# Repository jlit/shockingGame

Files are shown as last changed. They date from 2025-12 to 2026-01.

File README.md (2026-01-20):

# R^4 - A Shocking Game
A reaction, recall, roulette, and random game with consequences



# Description
This is an improvement over the ["Lightning Reaction Reloaded - Shocking Game"](https://www.amazon.com/dp/B0006B2Q50?ref=ppx_yo2ov_dt_b_fed_asin_title) available for $40 online.  In that game, players press the button on their controller when the game's random delay indicates.  The last player to respond gets an electric shock.  The game supports 2-4 players.

This improved version supports 2-5 players and adds three new game modes: "Recall", "Roulette", and "Random".  Recall similar to the old [Simon Game](https://en.wikipedia.org/wiki/Simon_(game)) from the 1970s.  In this mode, players must repeat an ever longer sequence.  This first player to mess up the sequence is shocked.  Roulette is a verison of Russian Roulette where one player presses their button and may or may not be shocked.  Random mode always shocks one player at random each round.

# Features
- Reaction Time game mode
- Recall Sequence game mode
- Russian Roulette game mode
- Random game mode
- Up to 5 players
- Variable intensity adjustment knob to control shock
- Digital intensity display
- 30 multi-colored LEDs
- Sound

# Play
Insert 8 AA batteries into the compartment on the bottom of the game.  Begin by turning the power switch to On.  A series of LED annimations should appear and the Intensity digital display should show a number from 1.50 to 6.90.  

__IMPORTANT: If the display shows more than 7 (volts) do not play the game.__

Turn the intensity knob to the desired level.  The digital display shows the voltage.  Under 3 voltages is barely detectable.  3 volts is "normal".  Use above 3 volts at your own risk.  6.9 volts is the maximum and hurts.

## Reaction Mode
Turn the game mode knob to Reaction and press the Number of Players button until the desired number (2-5) of player LEDs illuminate.  An LED animation (green sequence of lights for each active player) will illuminate for each player.  Each player should pick up a controller near illuminated LEDs and grasp it so that their hand touches both aluminum strips.  Turn the intensity knob to the desired level.  See above.

Press the Start button (big white button in center) to start a round of play.  A sound and animation will play, followed by a random length of quiet time (2-10 seconds) and then all the LEDs will turn white and a beep will sound.  Each player should press the button on the their controller as soon as they sense the lights and sound.  The LEDs will illuminate to indicate the order the buttons were pressed.  The player with the fastest reaction time will show 1 blue LED, the seconds fastest 2 blue LEDs, etc. until the last player.  That player will show 4 blinking red LEDs and will have received a 100 ms shock.

The game has cheat detection.  Any player who has their button depressed when the game switches from delay to all white LEDs will be deemed a cheater.  All 4 of their LEDs will blink red and they will receive a 1 second shock for cheating.

After 5 seconds, the game will again display LED animation and wait for the next press of the Start button for another round.

## Recall Mode
Turn the game mode knob to Recall and select the desired number of players (2-5).  An LED animation will illuminate (lighting up each player's LEDs in a random order).  Each player should pick up a controller near illuminated LEDs and grasp it so that their hand touches both aluminum strips.  Turn the intensity knob to the desired level.  See above.

Press the Start button (big white button in center) to start a round of play.  A single player's LEDs will illuminate in a color specific to that player, and a short sound will play.  That player has 5 seconds to press their button once.  If they do not press their button within 5 seconds their LEDs will flash red and they will receive a shock.  If a different player presses their button they will receive the same treatment.  Either way, the game is over at this point.  

If the proper player presses their button (and only that player), the game progresses.  The same player's sound and LED will again illuminate, followed by a second player's LED and sound (or maybe the first player's twice -- it is random).  The players again have 5 seconds between each item in the sequence to press their button.  If the sequence is not repeated correctly, the offending player is shocked, their LEDS are turned red and the game is over.  If the sequence is mimicked correctly, the game continues with 3 items in the sequence, etc. until a player makes a mistake.  Note: the time between items in the sequence gets slightly shorter with each round.

Five seconds after a mistake, the game will again display LED animation and wait for the next press of the Start button for another round.

## Russian Roulette Mode
Turn the game mode knob to Roulette and select the desired number of players (2-5).  An LED animation will illuminate (each player's 4 LEDs blue, one at a time, rotating around).  Each player should pick up a controller near illuminated LEDs and grasp it so that their hand touches both aluminum strips.

Press the Start button (big white button in center) to start a round of play.  In this mode, each player's LEDs illuminate white and the game waits for an active player to press their controller button.  When they do, they will receive a shock and their LEDs with blink red if they are the "target" player, otherwise their LEDs will turn green and no one will be shocked.

After 5 seconds, the game will again display the LED animation and wait for the next button press with a new random target player.

## Random Mode
Turn the game mode knob to Random and select the desired number of players (2-5).  An LED animation will illuminate (each player's 4 LEDs cyan, in a random order).  Each player should pick up a controller near illuminated LEDs and grasp it so that their hand touches both aluminum strips.

Press the Start button (big white button in center) to start a round of play.  A sound and animation will play, followed by a random length of quiet time (2-6 seconds) and then all the LEDs will turn white.  At this point,  one player will be shocked and their LEDs will turn red.  

After 5 seconds, the game will again display the LED animation and wait for the next button press with a new random target player.

# Build
The game uses an Arduino micro-controller to handle the logic.  The shock circuit is harvested from a toy shock pen and use a flyback transformer and oscillator operating at between 2.5-6 volts.  The controllers house a momentary button and two polished aluminum electrodes along the sides.  The base houses the control knobs, voltage display, LEDs, and center start button.  Most of the parts are 3D printed in PLA.

# Parts List
- [Arduino R4 Minima](https://www.amazon.com/Arduino-UNO-Minima-ABX00080-Connector/dp/B0C78K4CD4/ref=sr_1_3)
- [Battery Holder (8 AA)](https://www.amazon.com/dp/B07WP1CYYW)
- [Mini ON and Off Rocker Switch 12V 20A T85 2 Pin SPST](https://www.amazon.com/dp/B07S2QJKTX)
- [Momentary Tactile Push Button, 12 x 12 mm x 4.3 mm](https://www.amazon.com/TWTADE-Momentary-Tactile-Button-Switch/dp/B07CG6HVY9)
- [1 Pole 4 Position Rotary Switch (for game mode)](https://www.amazon.com/dp/B07JLRM2L7)
- [1K Linear Rotary Potentiometer (for intensity)](https://www.amazon.com/dp/B082FCFSHX)
- [LM2596 DC-DC Buck Converter Step Down Module Power Supply](https://www.amazon.com/Zixtec-LM2596-Converter-Module-1-25V-30V/dp/B07VVXF7YX)
- [3 Wire 0.36" DC 0~30V Digital Voltmeter Digital Red LED Display](https://www.amazon.com/dp/B079N98PY4)
- [WS2812B IC RGB Individual Addressable LED Strip Light](https://www.amazon.com/LOAMLIN-WS2812B-Individually-Addressable-Waterproof/dp/B0956C7KFR)
- [Momentary Stainless Steel Push Button On/Off (High Head)](https://www.amazon.com/dp/B08L49F7DV) (Quantity 6)
- [Aluminum Flat Plate Bar Stock 3 x 10 x 305mm T6511](https://www.amazon.com/dp/B0CZ4F77TL)
- [22 Gauge 4 Conductor Electrical Wire](https://www.amazon.com/dp/B0CFJXMDT3)
- [5V 6 Channel Relay Optocoupler Isolation Module](https://www.amazon.com/dp/B08RRTHTYQ)
- [Toy Shock Pen](https://www.amazon.com/dp/B0DZWW5TX7)
- Wire, solder, PLA filament, zip ties, screws, etc.

# Electrical Circuit
The game uses 8 AA batteries for 12v DC to power the Ardunio and a LM2596 DC-DC Buck Converter.  The output of the buck converter is controlled by an "intensity" rotary 0-1k poteniometer knob, resulting in 2-7v DC output to drive the shock circuits.  The output voltage is displayed on a 3 digit 8-segment display.  The shock circuit uses a flyback transformer (looks like a blue capacitor) and a small oscillator.  A single shock circuit is controlled by and isolated from the Arduino via an opto-isolated relay and the output from the shock circuit is relayed to a player's controller also via opto-isolated relays.  All buttons and switches are connected to GPIO pulled up pins on the Arduino and complete the circuit to ground.  The WS2812 LED strip uses 5v power from the Arduino and a single data GPIO pin to control the individually addressable LEDs.



 # CAD Designs
 All components of the game were designed in Autodesk Fusion 360.
 









# Build
## 3D print all the parts
- Base
- Base Top
- Battery Cover
- Start Button
- Start Button Mount
- Controller Handle (x5)
- Controller Cover (x5)
- Storage tray

## Shock Circuits
- To build the shock circuit, disassemble a toy shock pin by unscrewing the tip and breaking the middle black portion from the silver top portion.
- Using pliers for grip, pull the black tube out of the top.
- There will be a blue capacitor, a very small circuit board with a white oscillator dot in the middle, three small batteries, and a spring.
- Remove the blue capacitor by unbending the lower terminal wire.
- Solder two terminals of the capacitor to the pads on the circuit board they were touching when in the pen.
- Solder a wire to the other terminal of the capacitor.
- Solder two wires to the other two pads on the other end of the circuit board.
- If you apply 3-6 volts to those two wires and then touch the ground wire and the 3rd terminal of the capacitor you will receive a shock.
- Reuse the batteries for some other project.



## Controllers
- Prepare to build the controllers by cutting the aluminum bar stock to 60mm lengths for each electrode.  
- Drill and tap a hole for an M3 screw in each.  The holes should by 7mm from the top and 7mm from the outside edge of each bar.





- Round the outside corners of each and polish.
- Cut the 4-conductor wire into 5 30" lengths.
- Assemble all the parts (including 3mm screws and washers)



- Cut the wires from the buttons and remove any remaining heat shrink.
- Strip 90mm of the outside cover from one end of each wire and strip and tin the ends of each conductor.  
- For each controller,
  - Thread the button into the top of the controller.
  - insert the wires from the bottom.  
  - Solder two wires (red and white) to the two button terminals.
  - Using and M3 screw and washer, secure the other two wires to two electrode bars.
  - Secure a zip-tie around the 4-conductor wire where it exits the hole in the bottom of the controller.
  - Place the bars into the slots on the cover and slide the cover under the top of the controller.
  - Secure the cover in place with one M3 screw.

## LEDs
- Cut the WS2812 LED strip into 4 lengths of 4 LEDs.  Be sure to cut at designated cut lines on the strip.
- Solder 3 wires (5v, data, ground) between each strip.  Be certain to keep the arrows pointing in the same direction.
- Using a hot glue gun, glue the strips into the top of the game so that the LEDs align with the holes.
- Cover each strip with tape.





## Start Button
- CA glue the 12mm button switch to the start button mount panel with the pins sticking through the holes.
- Solder wires to two pins on one side of the switch.
- Place the start button into the top, cover, and attach the switch cover to the top with 5 screws.

## Knobs and Switches
- Solder wires to the terminals of the 3 position rotary game mode switch.
- Insert rotary switch into the top, place the label, secure with the provided washer and nut, and attach a knob.
- For the number of players button, insert the button into the top, place the label, secure with the provided nut from below.
- For the intensity control, the on-board potentiometer on the LM2596 DC-DC Buck Converter needs to be replaced with the 1k rotary potentiometer.
- Using a soldering iron, remove the blue pot.
- Solder wires to the 3 terminals of the 1k rotary pot and solder the other ends to the LM2596.
- Insert the rotary pot into the top, place the label, secure with the provided washer and nut, and attach a knob.
- Insert the digital voltage display into the top and secure with 2 m2 screws.
- Insert the power toggle switch into the side of the top unit.

## Wiring
- Thread each controller wire into the holes on the side of the top unit.
- Connect the switches, controllers, etc. according to the diagram above.



## Programming
- Download the code in the code folder to the Arduino

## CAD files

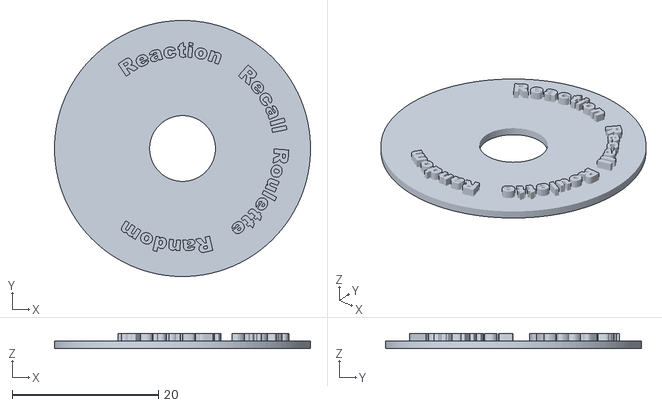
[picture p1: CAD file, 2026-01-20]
models/ReactionLabel.stl
35.0 x 35.0 x 2.00

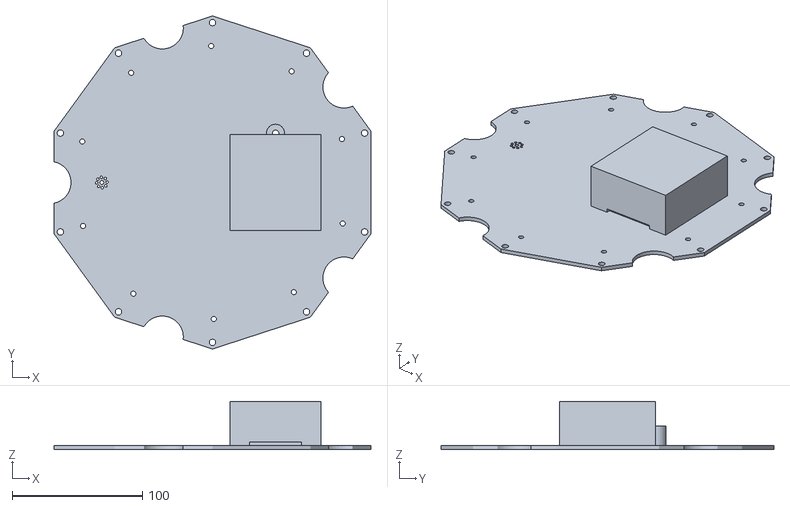
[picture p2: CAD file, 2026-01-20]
models/Base.stl
243.6 x 256.1 x 37.0

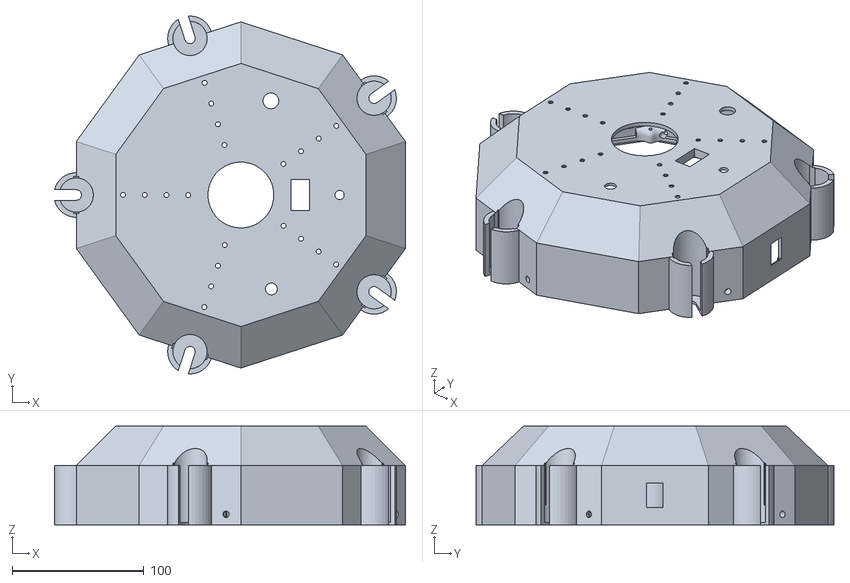
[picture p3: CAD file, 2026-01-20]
models/BaseTop.stl
266.5 x 271.7 x 75.0

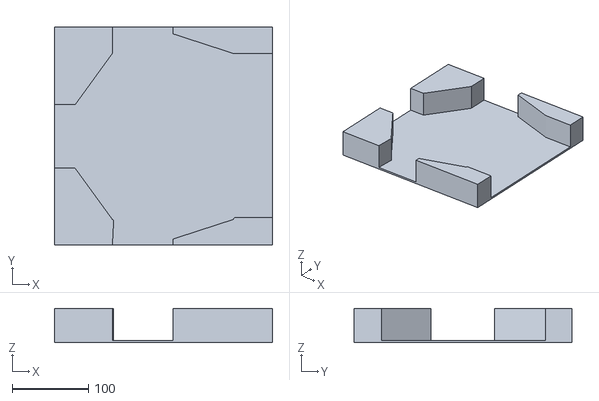
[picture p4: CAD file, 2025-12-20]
models/Holder.stl
285.8 x 285.8 x 45.0

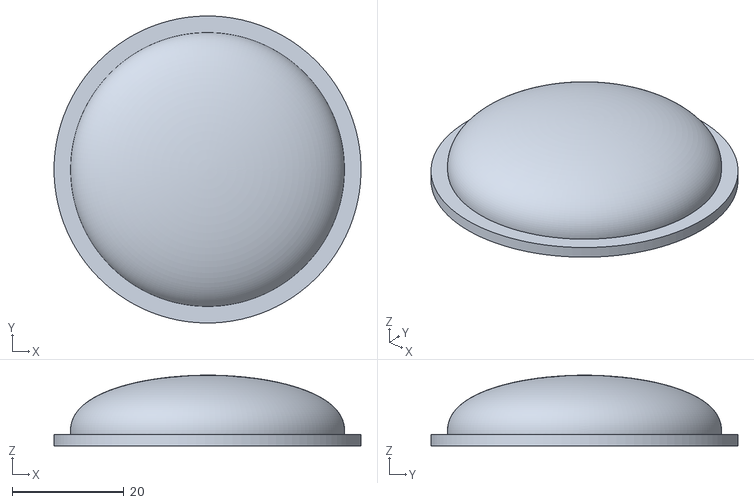
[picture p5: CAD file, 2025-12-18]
models/StartButton.stl
55.0 x 55.0 x 12.7

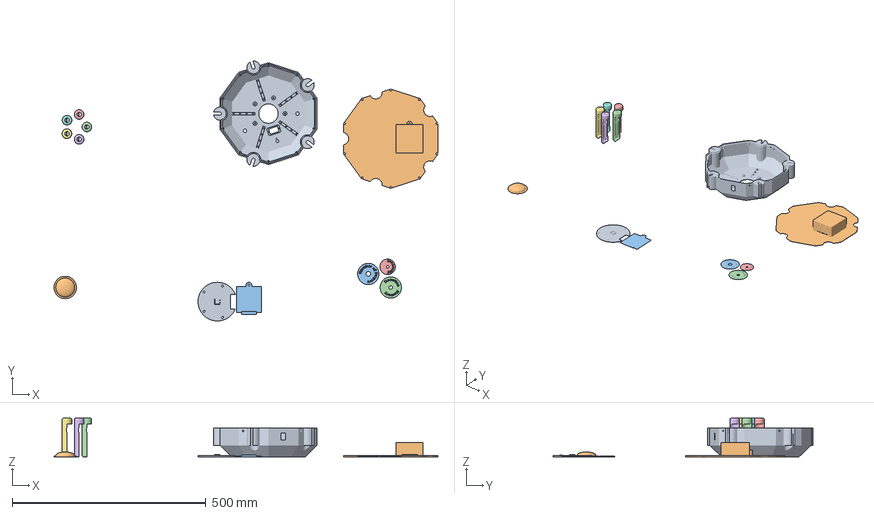
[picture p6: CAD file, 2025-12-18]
models/ShockGame.3mf
990.8 x 670.8 x 100.0 mm
ButtonMount.stl
Base.stl
BatteryLid.stl
Handle.stl x 5
BaseTop.stl
StartButton.stl
NumberOfPlayersLabel.stl
ReactionLabel.stl
IntensityLabel.stl

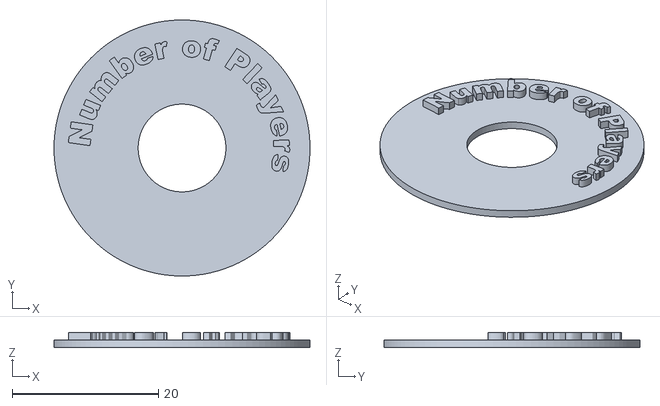
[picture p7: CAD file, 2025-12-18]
models/NumberOfPlayersLabel.stl
35.0 x 35.0 x 2.00

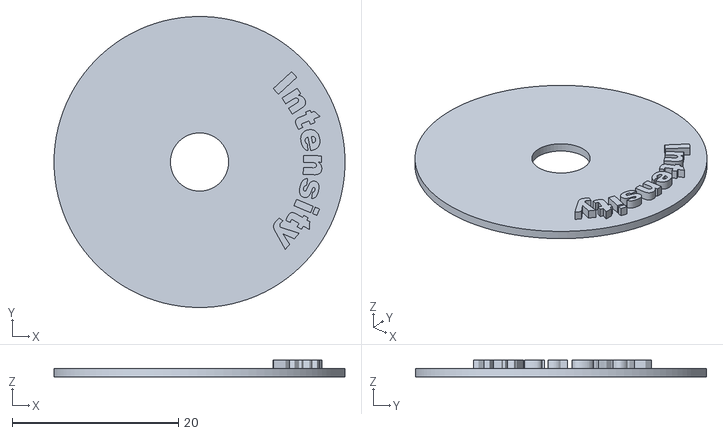
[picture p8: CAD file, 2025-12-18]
models/IntensityLabel.stl
35.0 x 35.0 x 2.00

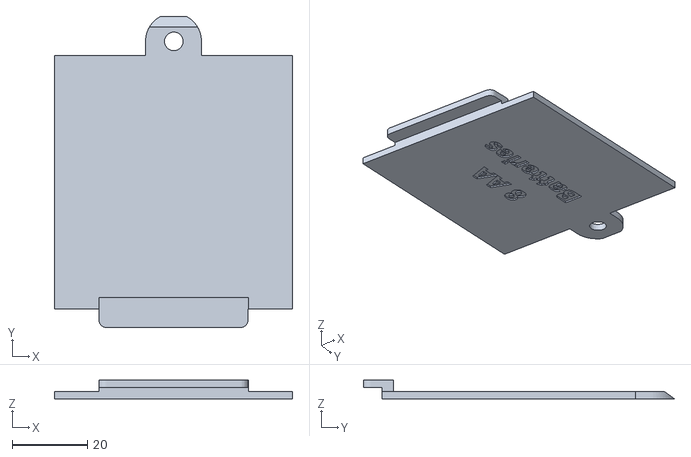
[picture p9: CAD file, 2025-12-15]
models/BatteryLid.stl
63.4 x 82.7 x 4.95

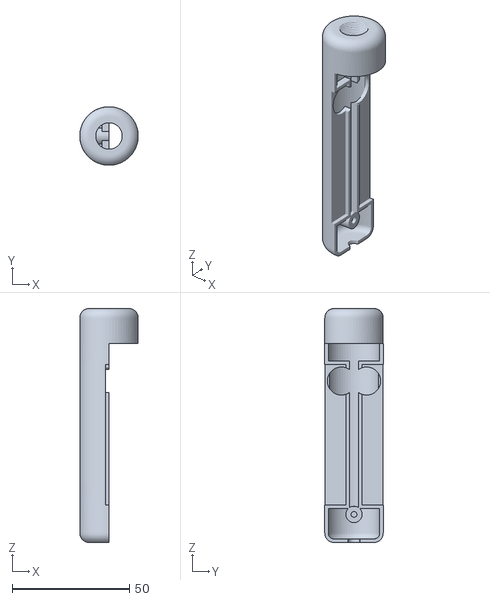
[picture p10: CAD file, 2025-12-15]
models/Handle.stl
25.0 x 25.0 x 100.0

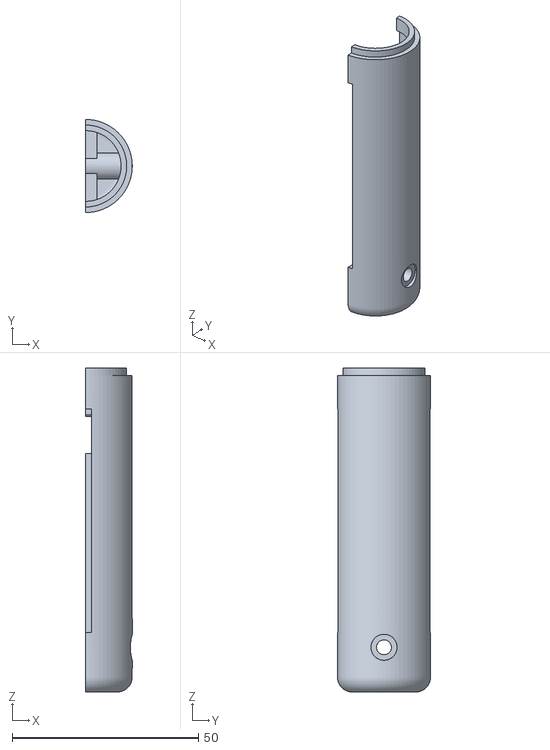
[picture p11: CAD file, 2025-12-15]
models/Cover.stl
12.5 x 25.0 x 87.0

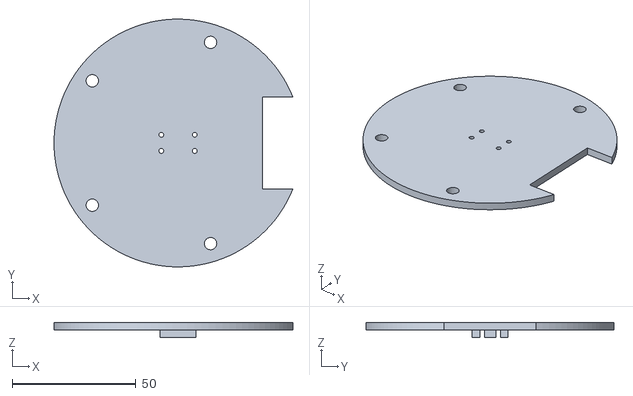
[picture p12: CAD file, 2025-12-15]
models/ButtonMount.stl
96.5 x 100.0 x 6.00

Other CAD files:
CAD/ShockingGame.f3d

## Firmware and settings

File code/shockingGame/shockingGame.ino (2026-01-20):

#include <math.h>
#include <FastLED.h>
#include "pitches.h"

#define MAX_PLAYERS 5

// LED stuff
#define NUM_LEDS 20
CRGBArray<NUM_LEDS> leds;
int LEDSequenceNumber = -1; // tracks where in an LED sequence we are so that it is non-blocking

// Global play options
int numberOfPlayers = 5;
const int numberOfLEDsPerPlayer = 4;
const int shockTime = 100; // SHOCK DURATION IN MS
const int maxDelayBetweenResponses = 5000;
const int debounceTime = 50;

// Pins
const int buttonStartPin = 7;
const int buttonNumberOfPlayersPin = 12;
const int LEDPin = 19;
const int shockRelayPin = A5;
const int modePins[4] = {8, 9, 10, 11}; // Reaction, Recall, Roulette, Random
const int buttonPins[MAX_PLAYERS] = {2, 3, 4, 5, 6};
const int shockPins[MAX_PLAYERS] = {A4, A3, A2, A1, A0};
const int buzzer = 13; 

enum State {
  WAITING,
  PLAYING,
  FINISHING
};
State currentState = WAITING;

enum Mode {
  REACTION,
  RECALL,
  ROULETTE,
  RANDOM
};
Mode currentMode = RECALL;

// Reaction mode settings
int pressed[MAX_PLAYERS] = {0, 0, 0, 0, 0};
int pressedTotal = 0;
int startTime;

// Recall mode settings
const CRGB playerColors[MAX_PLAYERS] = {CRGB::Orange, CRGB::Blue, CRGB::Yellow, CRGB::Green, CRGB::Cyan};
const int playerTones[MAX_PLAYERS] = {NOTE_G3, NOTE_C4, NOTE_E4, NOTE_G4, NOTE_F4};
int betweenRoundsDelay = 1500;
int sequenceDelay = 750;
int sequenceDecrement = 25;
int sequence[1000];
int sequenceLength = 0;

// ============================================================================
// State Management
// ============================================================================
void reset() {
  Serial.println (F("Resetting."));
  FastLED.clear(true);
  currentState = WAITING;
  for(int player = 0; player < MAX_PLAYERS; player++) {
    pressed[player] = 0;
  }
  pressedTotal = 0;
  sequenceLength = 0;
  LEDSequenceNumber = -1;
  sequenceDelay = 750;
  LEDsNumberOfPlayers();
  delay(1000);
}

bool settingsChanged() {
  bool changed = false;
  if(digitalRead(buttonNumberOfPlayersPin) == LOW) {
    numberOfPlayers++;
    if(numberOfPlayers > MAX_PLAYERS) {
      numberOfPlayers = 2;
    }
    Serial.print(F("number of players changed to "));
    Serial.println(numberOfPlayers);
    changed = true;
    delay(50); // to prevent bounce
  }
  for(int pin = 0; pin < 4; pin++) {
    if(digitalRead(modePins[pin]) == LOW) {
      if(pin != static_cast<int>(currentMode)) {
        Serial.print(F("game mode changed to "));
        Serial.println(pin);
        changed = true;
        currentMode = static_cast<Mode>(pin); // 0 = Reaction, 1 = Recall, 2 = Roulette, 3 = Random
      }
    }
  }
  if(changed) {
    Serial.println(F("Settings changed"));
  }
  return changed;
}
// ============================================================================

// ============================================================================
// Game Play
// ============================================================================
void waitForRouletteButton() {
  Serial.println(F("waiting for a roulette button press..."));
  int targetPlayer = random(0, numberOfPlayers);
  Serial.print(F("target player is "));
  Serial.println(targetPlayer);
  while (pressedTotal == 0) {
    for(int playerNum = 0; playerNum < numberOfPlayers; playerNum++) {
      if (digitalRead(buttonPins[playerNum]) == LOW) {
        FastLED.clear(true);
        pressedTotal = 1;
        Serial.print(F("Button "));
        Serial.print(playerNum);
        Serial.println(F(" was pressed."));
        if(playerNum == targetPlayer) {
          shockPlayer(playerNum);
        }
        else {
          LEDsPlayerOneColor(playerNum, CRGB::Green);
          playSuccess();
          delay(2000);
        }
      }
    }
  }
}

void repeatSequenceItem(int itemNumber) {
  Serial.print("Repeating Item ");
  Serial.print(itemNumber);
  Serial.print(" (");
  Serial.print(sequence[itemNumber]);
  Serial.println(")");
  LEDsPlayerOneColor(sequence[itemNumber], playerColors[sequence[itemNumber]]);
  tone(buzzer, playerTones[sequence[itemNumber]], 300);
  delay(sequenceDelay);
  FastLED.clear(true);
}

void repeatSequence() {
  logSequence(0);
  FastLED.clear(true);
  for(int seq = 0; seq < sequenceLength; seq++) {
    repeatSequenceItem(seq);
    if(settingsChanged()) {
      reset();
    }
  }
}

void addItemToSequence() {
  FastLED.clear(true);
  int nextPlayerInSequence = random(numberOfPlayers);
  Serial.print(F("player "));
  Serial.print(nextPlayerInSequence);
  Serial.println(F(" is next in the sequence"));
  sequence[sequenceLength] = nextPlayerInSequence;
  repeatSequenceItem(sequenceLength);
  sequenceLength++;
  if(sequenceDelay > 200) { sequenceDelay = sequenceDelay - sequenceDecrement; } // Speed up as we go.  To a point.
}

void logSequence(int sequenceNumber) {
  Serial.print("Sequence: [");
  for(int i = 0; i < sequenceLength; i++) {
    Serial.print(sequence[i]);
    Serial.print(", ");
  }
  Serial.println("]");

  Serial.print("At position ");
  Serial.print(sequenceNumber);
  Serial.print(" expecting ");
  Serial.println(sequence[sequenceNumber]);
}

void waitForSequenceRepeat() {
  FastLED.clear(true);
  int sequenceNumber = 0;
  int lastButtonPress = millis();
  logSequence(sequenceNumber);

  while(currentState == PLAYING && sequenceNumber < sequenceLength) {
    for(int playerNum = 0; playerNum < numberOfPlayers; playerNum++) {
      if(digitalRead(buttonPins[playerNum]) == LOW) {
        // Only debounce if same player as last press
        if(millis() - lastButtonPress > debounceTime || sequenceNumber == 0 || sequence[sequenceNumber-1] != playerNum) { 
          if(playerNum == sequence[sequenceNumber]) {
            Serial.print(F("Player "));
            Serial.print(playerNum);
            Serial.print(F(" correctly pressed their button for sequence item "));
            Serial.println(sequenceNumber);
            repeatSequenceItem(sequenceNumber);
            sequenceNumber++;
            logSequence(sequenceNumber);
          }
          else {
            Serial.print(F("player "));
            Serial.print(playerNum);
            Serial.print(F(" pressed their button when we were expecting player "));
            Serial.println(sequence[sequenceNumber]);
            shockPlayer(playerNum);
            currentState = FINISHING;
          }
        }
        lastButtonPress = millis();
      }
  
      if(settingsChanged()) {
        currentState = FINISHING;
      }
    }

    if(millis() - lastButtonPress > maxDelayBetweenResponses) {
      Serial.print(F("player "));
      Serial.print(sequence[sequenceNumber]);
      Serial.println(F(" failed to press their button in time "));
      shockPlayer(sequence[sequenceNumber]);
      currentState = FINISHING;
    }

    if(settingsChanged()) {
      currentState = FINISHING;
    }
  }
}

bool checkCheater() {
  bool cheater = false;
  for(int playerNum = 0; playerNum < numberOfPlayers; playerNum++) {
    // A cheater has their button pressed when the game is about to start
    // Only the first cheater is punished 
    if (!cheater && digitalRead(buttonPins[playerNum]) == LOW) {
      cheater = true;
      shockCheater(playerNum);
    }
  }
  return cheater;
}

void waitForReactions() {
  Serial.println(F("Waiting for reactions..."));
  while (currentState == PLAYING  && pressedTotal < numberOfPlayers - 1) {
    for(int playerNum = 0; playerNum < numberOfPlayers; playerNum++) {
      if(digitalRead(buttonPins[playerNum]) == LOW) {
        if(pressed[playerNum] == 0) {
          pressed[playerNum] = 1;
          pressedTotal = pressedTotal + 1;
          LEDsPlayerPosition(playerNum, pressedTotal-1);
          Serial.print(F("Button "));
          Serial.print(playerNum);
          Serial.print(F(" was pressed in "));
          Serial.print(millis() - startTime);
          Serial.println(F(" millseconds"));
        }
      }
    }

    if(millis() - startTime > maxDelayBetweenResponses) {
      Serial.println(F("Time expired without a press"));
      for(int playerNum = 0; playerNum < numberOfPlayers; playerNum++) {
        if(pressed[playerNum] == 0) {
          Serial.print(F("player "));
          Serial.print(playerNum);
          Serial.println(F(" failed to press their button in time "));
        }
      }
      currentState = FINISHING;
    }

    if(settingsChanged()) {
      currentState = FINISHING;
    }
  }
}

void shockingTime() {
  noTone(buzzer);

  for(int playerNum = 0; playerNum < numberOfPlayers; playerNum++) {
    // Shock any player who deserves it (might be many if they all failed to press their button)
    if (pressed[playerNum] == 0) {
      int shockPin = shockPins[playerNum];

      Serial.print(F("Shocking player "));
      Serial.println(playerNum);
      digitalWrite (shockPin, HIGH);
      LEDsPlayerOneColor(playerNum, CRGB::Red);
    }
  }

  playFail();
  delay(shockTime); // Wait for all

  // Turn them all off
  for(int playerNum = 0; playerNum < numberOfPlayers; playerNum++) {
    if (pressed[playerNum] == 0) {
      int shockPin = shockPins[playerNum]; 
      digitalWrite (shockPin, LOW);
    }
  }
}

void shockCheater(int playerNum) {
  int shockPin = shockPins[playerNum];

  Serial.print(F("Player "));
  Serial.print(playerNum);
  Serial.println(F(" cheated."));

  noTone(buzzer);
  LEDsPlayerOneColor(playerNum, CRGB::Red);

  digitalWrite (shockRelayPin, HIGH);
  digitalWrite (shockPin, HIGH);
  delay(1000); // cheaters get a full second
  digitalWrite (shockPin, LOW);
  digitalWrite (shockRelayPin, LOW);

  playBoom();
  LEDsPlayerFlashOneColor(playerNum, CRGB::Red);

  currentState = FINISHING;
}

void shockPlayer(int playerNum) {
  int shockPin = shockPins[playerNum];

  Serial.print(F("Shocking player "));
  Serial.println(playerNum);

  noTone(buzzer);
  digitalWrite (shockRelayPin, HIGH);
  digitalWrite (shockPin, HIGH);
  playFail();
  LEDsPlayerOneColor(playerNum, CRGB::Red);
  delay(shockTime);
  digitalWrite (shockPin, LOW);
  digitalWrite (shockRelayPin, LOW);
  LEDsPlayerFlashOneColor(playerNum, CRGB::Red);
}
// ============================================================================

// ============================================================================
// LED Stuff
// ============================================================================
void LEDsTest(CRGB color) {
  for(int i = 0; i < MAX_PLAYERS * numberOfLEDsPerPlayer; i++) {
    leds[i] = color;
    FastLED.show();
    delay(50);
  }
}

void LEDsNumberOfPlayers() {
  FastLED.clear();
  for(int player = 0; player < numberOfPlayers; player++) {
    leds[player*numberOfLEDsPerPlayer] = CRGB::Green;
  }
  FastLED.show();
}

void LEDsPlayerPosition(int player, int position) {
  for(int led = 0; led < numberOfLEDsPerPlayer; led++) {
    if(led <= position) {
      leds[player*numberOfLEDsPerPlayer+led] = CRGB::Blue;
    }
    else {
      leds[player*numberOfLEDsPerPlayer+led] = CRGB::Black;
    }
  }
  FastLED.show();
}

void LEDsPlayerOneColor(int player, CRGB color) {
  for(int led = 0; led < numberOfLEDsPerPlayer; led++) {
    leds[player*numberOfLEDsPerPlayer+led] = color;
  }
  FastLED.show();
}

void LEDsPlayerFlashOneColor(int player, CRGB color) {
  for (int x = 0; x < 10; x++) {
    LEDsPlayerOneColor(player, color);
    delay(150);
    
    LEDsPlayerOneColor(player, CRGB::Black);
    delay(150);
  }
  LEDsPlayerOneColor(player, color);
}

void LEDsAllOneColor(CRGB color) {
  for(int player = 0; player < numberOfPlayers; player++) {
    for(int led = 0; led < numberOfLEDsPerPlayer; led++) {
      leds[player*numberOfLEDsPerPlayer+led] = color;
    }
  }
  FastLED.show();
}

void LEDsAllSequential(CRGB color) {
  for(int player = 0; player < numberOfPlayers; player++) {
    if(LEDSequenceNumber < 0) {
      FastLED.clear(true);
    }
    else {
      for(int led = 0; led < LEDSequenceNumber+1; led++) {
        leds[player*numberOfLEDsPerPlayer+led] = color;
      }
    }
  }
  LEDSequenceNumber++;
  if(LEDSequenceNumber > numberOfLEDsPerPlayer-1) {
    LEDSequenceNumber = -1;
  }
  FastLED.show();
  delay(150);
}

void LEDsAllRadial(CRGB color) {
  if(LEDSequenceNumber < 0) {
    LEDSequenceNumber = 0;
  }
  int player = LEDSequenceNumber;
  FastLED.clear(true);
  for(int led = 0; led < numberOfLEDsPerPlayer; led++) {
    leds[player*numberOfLEDsPerPlayer+led] = color;
  }
  LEDSequenceNumber++;
  if(LEDSequenceNumber > numberOfPlayers-1) {
    LEDSequenceNumber = 0;
  }
  FastLED.show();
  delay(150);
}

void LEDsRandomPlayer(CRGB color) {  
  int player = random(numberOfPlayers);
  if(color == CRGB::Black) { // If we passed in black then use the Recall game color for each player
    color = playerColors[player];
  }
  FastLED.clear(true);
  for(int led = 0; led < numberOfLEDsPerPlayer; led++) {
    leds[player*numberOfLEDsPerPlayer+led] = color;
  }
  FastLED.show();
  delay(150);
}
// ============================================================================

// ============================================================================
// Sound Stuff
// ============================================================================
void playBoom() {
  tone(buzzer, 31, 1500);
}

void playFail() {
  tone(buzzer, 392, 450);
  // delay(450);
  tone(buzzer, 262, 900);
  // delay(900);
  // noTone(buzzer);
}

void playSuccess() {
  const uint8_t NOTE_SUSTAIN = 50; 
  for(uint8_t nLoop = 0; nLoop < 2; nLoop ++) {
    tone(buzzer,NOTE_A5);
    delay(NOTE_SUSTAIN);
    tone(buzzer,NOTE_B5);
    delay(NOTE_SUSTAIN);
    tone(buzzer,NOTE_C5);
    delay(NOTE_SUSTAIN);
    tone(buzzer,NOTE_B5);
    delay(NOTE_SUSTAIN);
    tone(buzzer,NOTE_C5);
    delay(NOTE_SUSTAIN);
    tone(buzzer,NOTE_D5);
    delay(NOTE_SUSTAIN);
    tone(buzzer,NOTE_C5);
    delay(NOTE_SUSTAIN);
    tone(buzzer,NOTE_D5);
    delay(NOTE_SUSTAIN);
    tone(buzzer,NOTE_E5);
    delay(NOTE_SUSTAIN);
    tone(buzzer,NOTE_D5);
    delay(NOTE_SUSTAIN);
    tone(buzzer,NOTE_E5);
    delay(NOTE_SUSTAIN);
    tone(buzzer,NOTE_E5);
    delay(NOTE_SUSTAIN);
  }
  noTone(buzzer);
}

void playShortBeep() {
  tone(buzzer, 700, 250);
}

void playLongBeep() {
  tone(buzzer, 700, 750);
}
// ============================================================================

// Main program
void setup() {
  Serial.begin (9600);
  randomSeed(analogRead(A1));
  FastLED.addLeds<WS2812, LEDPin, GRB>(leds, NUM_LEDS);
  pinMode(buttonStartPin, INPUT_PULLUP);
  pinMode(buzzer, OUTPUT);
  for(int modePin = 0 ; modePin < 4; modePin++) {
    pinMode(modePins[modePin], INPUT_PULLUP);
  }
  pinMode(buttonNumberOfPlayersPin, INPUT_PULLUP);
  for(int buttonPin = 0 ; buttonPin < MAX_PLAYERS; buttonPin++) {
    pinMode(buttonPins[buttonPin], INPUT_PULLUP);
  }
  pinMode(shockRelayPin, OUTPUT);
  for(int shockPin = 0 ; shockPin < MAX_PLAYERS; shockPin++) {
    pinMode(shockPins[shockPin], OUTPUT);
  }
  LEDsTest(CRGB::Green);
  FastLED.clear(true);
  Serial.println(F("Setup complete"));
}

void loop() {
  Serial.println (F("Stand-by waiting for start button..."));

  if(settingsChanged()) {
    reset();
  }

  while (digitalRead(buttonStartPin) == HIGH) {
    if(currentMode == REACTION) {
      LEDsAllSequential(CRGB::Green);
    }
    if(currentMode == RECALL) {
      LEDsRandomPlayer(CRGB::Black);  // Actually uses playeColors
    }
    if(currentMode == ROULETTE) {      
      LEDsAllRadial(CRGB::Blue);
    }
    if(currentMode == RANDOM) {
      LEDsRandomPlayer(CRGB::Cyan);
    }
    if(settingsChanged()) {
      reset();
    }
  }

  currentState = PLAYING;

  if(currentMode == RANDOM) {
    Serial.println (F("Starting Random mode..."));
    LEDsAllOneColor(CRGB::White);
    
    FastLED.clear(true);
    for (int i = 20; i < 255; i++) { // GAME START BUZZER SOUND
      tone(buzzer, i * 7);
      delay(15);
    }
    noTone(buzzer);
    FastLED.clear(true);

    delay(random(2000, 6000));  // Wait 2-6 seconds
    Serial.println(F("Random wait over"));

    if(currentState == PLAYING) {
      shockPlayer(random(numberOfPlayers));
    }
    reset();
  }

  if(currentMode == ROULETTE) {
    Serial.println (F("Starting Russian roulette mode..."));
    LEDsAllOneColor(CRGB::White);
    waitForRouletteButton();
    reset();
  }

  if(currentMode == REACTION) {
    Serial.println (F("Starting reaction game countdown..."));
    FastLED.clear(true);
    for (int i = 20; i < 255; i++) { // GAME START BUZZER SOUND
      tone(buzzer, i * 7);
      // LEDsAllSequential(CRGB::Green);
      delay(15);
    }
    noTone(buzzer);
    FastLED.clear(true);

    delay(random(2000, 10000));  // Wait 2-10 seconds
    Serial.println(F("Random wait over"));

    if(currentState == PLAYING) {
      Serial.println (F("Checking for cheaters..."));
      if(!checkCheater()) {
        Serial.println (F("Game start!"));
        startTime = millis();
        LEDsAllOneColor(CRGB::White);
        tone(buzzer, 3000);
      
        waitForReactions();

        Serial.print(F("Total buttons pressed: "));
        Serial.println(pressedTotal);

        for(int playerNum = 0; playerNum < numberOfPlayers; playerNum++) {
          Serial.print(F("Player "));
          Serial.print(playerNum);
          Serial.print(F(" pressed? - "));
          Serial.println(pressed[playerNum]);
        }
        
        shockingTime();
      }

      delay(5000);
      reset();
    }
  }

  if(currentMode == RECALL) {
    Serial.println (F("Starting recall game..."));
    FastLED.clear(true);
    LEDsAllOneColor(CRGB::Blue);
    playSuccess();
    delay(betweenRoundsDelay);
    FastLED.clear(true);
    while(currentState == PLAYING) {
      Serial.println(F("Another round of recall..."));
      repeatSequence();
      addItemToSequence();
      waitForSequenceRepeat();
      if(currentState == PLAYING) {
        FastLED.clear(true);
        playSuccess();
        delay(betweenRoundsDelay);
      }
    }
  }

  if(currentState == FINISHING) {
    reset();
  }
}

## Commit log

2025-12-16 Update README.md - New circuit (R4 Minima)
2025-12-18 Update README.md - Specify LED animations, list push button for number of players
2025-12-18 Updated CAD. Sounds in code.
    [Handle2.stl, IntensityLabel.stl, NumberOfPlayersLabel.stl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]
2025-12-20 Update README.md - Typos and Relays
2025-12-20 Update README.md - Fix link to relays
2025-12-20 Add holder model and update Fusion file
    [Holder.stl]
2025-12-24 Fix bug where last player does not get buzzed in recall mode and increase the sequence decrement
    [shockingGame.ino]
2025-12-24 undo improper fix for random to num players. Reset delay
    [shockingGame.ino]
2026-01-20 Add random mode and use new circuit diagram with single shock circuit
2026-01-20 Remove twinkle, add random mode, add shocking relay, tweak CAD to remove holiday message, drop start button mounts, new mode label
    [Base.stl, BaseTop.stl, ReactionLabel.stl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]
